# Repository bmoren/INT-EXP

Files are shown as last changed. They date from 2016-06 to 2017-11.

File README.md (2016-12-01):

# INT EXP
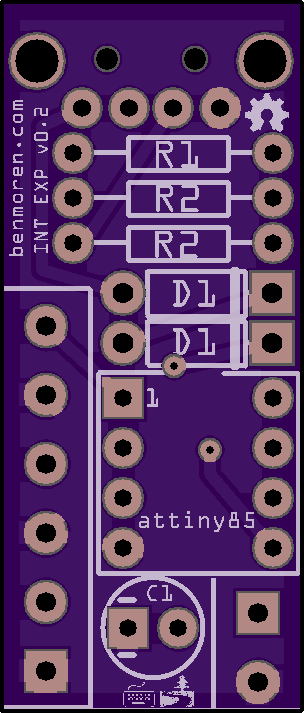
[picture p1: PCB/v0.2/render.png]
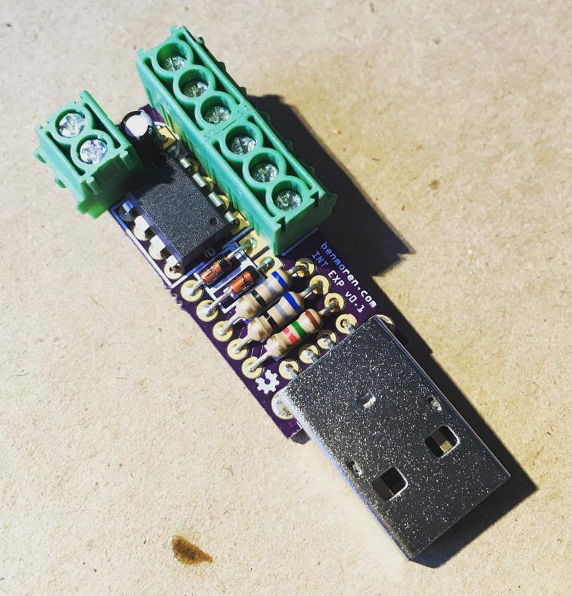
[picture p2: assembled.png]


screen &amp; physical interaction experimentation board

based on [v-usb](https://www.obdev.at/products/vusb/index.html) and the [ATtiny85](http://www.atmel.com/devices/attiny85.aspx)

with thanks to the [easy logger project](https://www.obdev.at/products/vusb/easylogger.html) and the [4 key keyboard project](http://blog.flipwork.nl/?x=entry:entry100224-003937)

[Build of Materials](https://docs.google.com/spreadsheets/d/1fC4rKzH0t7pgVtuNgmvmoYLOOsRQa8CITz7sNQLkrys/edit#gid=0)

### to compile and upload:
1. install [crosspack](https://www.obdev.at/products/crosspack/index.html)
1. pop an [ATtiny85](http://www.atmel.com/devices/attiny85.aspx) into the [usbtiny](https://www.sparkfun.com/products/11801) programmer
1. `cd` to this directory
1. `make fuse` Make the temporary 3 pin fuses with i/o on pin 4 for testing, (For the final fuse config, see below.)
1. `make flash` Flash the main.c file to the board.
1. `make resetfuse`
  + uses the final 4 pin i/o for final deployment. NOTE: this will disable the ATtiny from being re-programmable without a high voltage programmer. This must be completed after `make flash` or you will not be able to program the board!
1. `make clean` Delete all of the files used to build the main.hex file for programming.

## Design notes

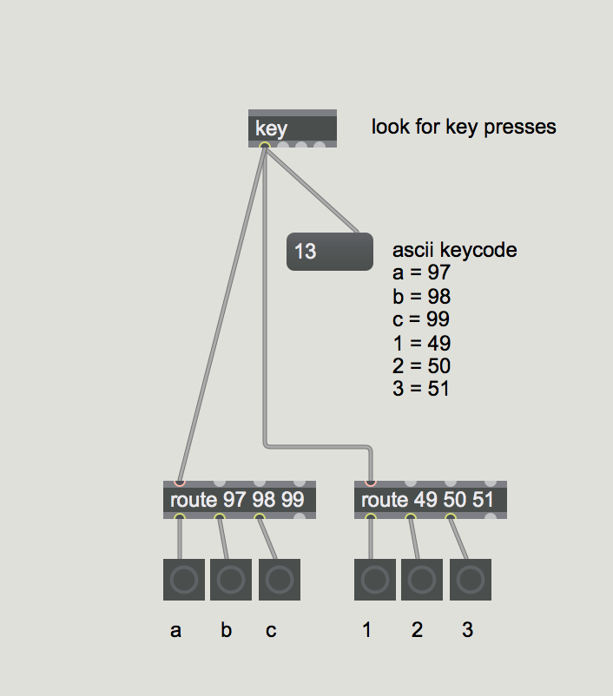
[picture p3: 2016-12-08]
examples/MAX-MSP/maxmsp.png

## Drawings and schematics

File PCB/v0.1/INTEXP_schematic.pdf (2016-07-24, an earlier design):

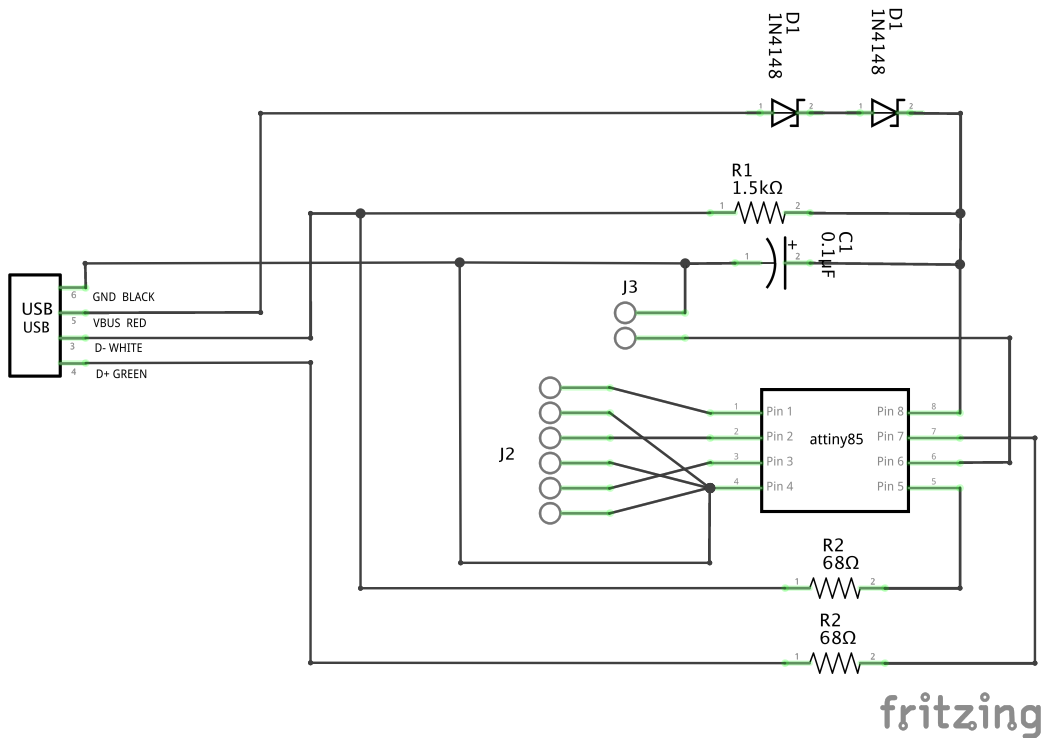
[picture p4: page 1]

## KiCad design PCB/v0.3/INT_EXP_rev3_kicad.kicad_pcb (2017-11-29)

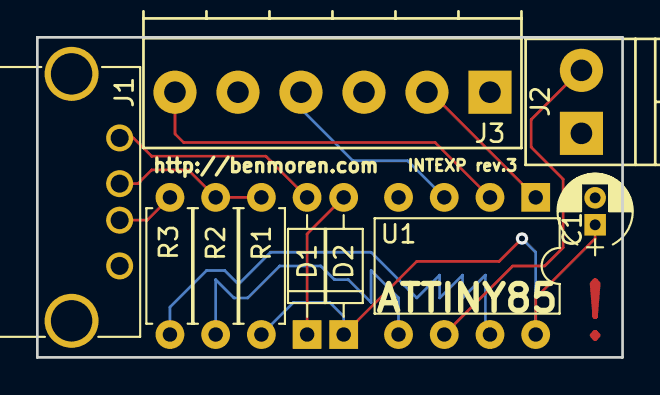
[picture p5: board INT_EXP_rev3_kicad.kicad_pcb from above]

Board: 2 copper layers, 32.5 x 17.8 mm, 10 parts (0 on the bottom side), 12 nets.

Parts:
C1: 0.1uf; CP_Radial_D4.0mm_P1.50mm
D1, D2: 1N4148; D_DO-35_SOD27_P7.62mm_Horizontal
J1: USB_A
J2: TOGGLE; TerminalBlock_Phoenix_PT-3.5mm_2pol
J3: ABC123; TerminalBlock_Phoenix_PT-3.5mm_6pol
R1: 1.5k; R_Axial_DIN0207_L6.3mm_D2.5mm_P7.62mm_Horizontal
R2, R3: 68; R_Axial_DIN0207_L6.3mm_D2.5mm_P7.62mm_Horizontal
U1: ATTINY85-20PU; DIP-8_W7.62mm

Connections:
GNDREF: C1.2, J1.4, J2.1, J3.1, J3.3, J3.5, U1.4
unnamed: C1.1, D2.1, R1.1, U1.8
unnamed: D1.1, D2.2
unnamed: D1.2, J1.1
unnamed: J1.2, R1.2, R2.2
unnamed: J1.3, R3.2
unnamed: J2.2, U1.6
unnamed: J3.2, U1.1
unnamed: J3.4, U1.3
unnamed: J3.6, U1.2
unnamed: R2.1, U1.5
unnamed: R3.1, U1.7

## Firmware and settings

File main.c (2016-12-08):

/* Name: main.c
 * Project: abc-123-intExp
 * Author: Ben Moren http://benmoren.com,
 * Thanks to Flip van den Berg - www.flipwork.nl - for a similar project which served as reference and a starting point for this project.
 * Creation Date: February 2010
 * Based on V-USB drivers from Objective Developments - http://www.obdev.at/products/vusb/index.html
 */


/*

IMPORTANT: 	This project uses fuse settings that disable the reset pin in order to use it as an IO pin.
			This means that if you can only re-program the AVR afterwards using High Voltage Serial Programming (HVSP)
			If you have a programmer that only supports ISP make sure to upload the firmware before setting the reset-disable fuse!

Working fuse setting on ATTiny45/85:

//to disable reset and enable 4 I/O
EXTENDED: 0xFF
HIGH:	 0x5F
LOW:	 0xC1

//for testing with 3 pins of I/O
EXTENDED: 0xFF
HIGH:	 0xdF
LOW:	 0xC1

*/

#include <avr/io.h>
#include <avr/wdt.h>
#include <avr/eeprom.h>
#include <avr/interrupt.h>
#include <avr/pgmspace.h>
#include <util/delay.h>
#include <stdlib.h>

#include "usbdrv/usbdrv.h"

#define BUTTON_PORT_B1 PORTB       /* PORTx - register for BUTTON 1 output */
#define BUTTON_PIN_B1 PINB         /* PINx - register for BUTTON 1 input */
#define BUTTON_BIT_B1 PB1          /* bit for BUTTON 1 input/output */

#define BUTTON_PORT_B2 PORTB       /* PORTx - register for BUTTON 2 output */
#define BUTTON_PIN_B2 PINB         /* PINx - register for BUTTON 2 input */
#define BUTTON_BIT_B2 PB4          /* bit for BUTTON 2 input/output */

#define BUTTON_PORT_B3 PORTB       /* PORTx - register for BUTTON 3 output */
#define BUTTON_PIN_B3 PINB         /* PINx - register for BUTTON 3 input */
#define BUTTON_BIT_B3 PB5          /* bit for BUTTON 3 input/output */

#define BUTTON_PORT_B4 PORTB       /* PORTx - register for BUTTON 4 output */
#define BUTTON_PIN_B4 PINB         /* PINx - register for BUTTON 4 input */
#define BUTTON_BIT_B4 PB3          /* bit for BUTTON 4 input/output */

/* ------------------------------------------------------------------------- */

static uchar    reportBuffer[8] = {0,0,0,0,0,0,0,0};    /* buffer for HID reports */

/* Reportbuffer format:

	0  Modifier byte
	1  reserved
	2  keycode array (0)
	3  keycode array (1)
	4  keycode array (2)
	5  keycode array (3)
	6  keycode array (4)
	7  keycode array (5)

	<< This is the standard usb-keyboard reportbuffer. It allows for 6 simultaneous keypresses to be detected (excl. modifier keys). In this application we only use 1, so the last 5 bytes in this buffer will always remain 0. >>
	<< I decided not to optimize this in order to make it easy to add extra keys that can be pressed simultaneously>>

   Modifier byte: 8 bits, each individual bit represents one of the modifier keys.

   	bit0  LEFT CTRL		(1<<0)
	bit1  LEFT SHIFT	(1<<1)
	bit2  LEFT ALT		(1<<2)
	bit3  LEFT GUI		(1<<3)
	bit4  RIGHT CTRL	(1<<4)
	bit5  RIGHT SHIFT	(1<<5)
	bit6  RIGHT ALT		(1<<6)
	bit7  RIGHT GUI		(1<<7)

	an example of a reportBuffer for a CTRL+ALT+Delete keypress:

	{((1<<0)+(1<<2)),0,76,0,0,0,0,0}

	the first byte holds both the LEFT CTRL and LEFT  modifier keys the 3rd byte holds the delete key (== decimal 76)

*/

static uchar    idleRate;           /* in 4 ms units */
static uchar    newReport = 0;		/* current report */

static uchar    buttonState_B1 = 3;		/*  stores state of button 0 */
static uchar    buttonState_B2 = 3;		/*  stores state of button 1 */
static uchar    buttonState_B3 = 3;		/*  stores state of button 2 */
static uchar    buttonState_B4 = 3;		/*  stores state of button 3 */

static uchar    buttonChanged_B1;
static uchar    buttonChanged_B2;
static uchar    buttonChanged_B3;
static uchar    buttonChanged_B4;

static uchar	debounceTimeIsOver = 1;	/* for switch debouncing */

static uchar  abc123 = 1; //start in 123 mode



/* ------------------------------------------------------------------------- */

const PROGMEM char usbHidReportDescriptor[USB_CFG_HID_REPORT_DESCRIPTOR_LENGTH] = {
    0x05, 0x01,                    // USAGE_PAGE (Generic Desktop)
    0x09, 0x06,                    // USAGE (Keyboard)
    0xa1, 0x01,                    // COLLECTION (Application)
    0x05, 0x07,                    //   USAGE_PAGE (Keyboard)
    0x19, 0xe0,                    //   USAGE_MINIMUM (Keyboard LeftControl)
    0x29, 0xe7,                    //   USAGE_MAXIMUM (Keyboard Right GUI)
    0x15, 0x00,                    //   LOGICAL_MINIMUM (0)
    0x25, 0x01,                    //   LOGICAL_MAXIMUM (1)
    0x75, 0x01,                    //   REPORT_SIZE (1)
    0x95, 0x08,                    //   REPORT_COUNT (8)
    0x81, 0x02,                    //   INPUT (Data,Var,Abs)	** Modifier Byte **
    0x95, 0x01,                    //   REPORT_COUNT (1)
    0x75, 0x08,                    //   REPORT_SIZE (8)
    0x81, 0x03,                    //   INPUT (Cnst,Var,Abs)	** Reserved Byte **
    0x95, 0x05,                    //   REPORT_COUNT (5)
    0x75, 0x01,                    //   REPORT_SIZE (1)
    0x05, 0x08,                    //   USAGE_PAGE (LEDs)
    0x19, 0x01,                    //   USAGE_MINIMUM (Num Lock)
    0x29, 0x05,                    //   USAGE_MAXIMUM (Kana)
    0x91, 0x02,                    //   OUTPUT (Data,Var,Abs)	** LED Report **
    0x95, 0x01,                    //   REPORT_COUNT (1)
    0x75, 0x03,                    //   REPORT_SIZE (3)
    0x91, 0x03,                    //   OUTPUT (Cnst,Var,Abs)	** LED Report Padding **
    0x95, 0x06,                    //   REPORT_COUNT (6)		** here we define the maximum number of simultaneous keystrokes we can detect **
    0x75, 0x08,                    //   REPORT_SIZE (8)
    0x15, 0x00,                    //   LOGICAL_MINIMUM (0)
    0x25, 0x65,                    //   LOGICAL_MAXIMUM (101)
    0x05, 0x07,                    //   USAGE_PAGE (Keyboard)
    0x19, 0x00,                    //   USAGE_MINIMUM (Reserved (no event indicated))
    0x29, 0x65,                    //   USAGE_MAXIMUM (Keyboard Application)
    0x81, 0x00,                    //   INPUT (Data,Ary,Abs)	** Key arrays (6 bytes) **
    0xc0                           // END_COLLECTION
};

static void timerPoll(void)
{
	static unsigned int timerCnt;

    if(TIFR & (1 << TOV1)){
        TIFR = (1 << TOV1); /* clear overflow */
        if(++timerCnt >= 5){       // 5/63 sec delay for switch debouncing
			timerCnt = 0;
			debounceTimeIsOver = 1;
        }
    }
}

static void buildReport(void){

	uchar key;

	if(newReport == 0){
		if (buttonChanged_B1 == 1){
      if (buttonState_B1 != 0){ // if button 1 is released
				// key = 0; //button released event
        abc123 = 0;
			}else { //if button 1 is pressed
				// key = 30; // key = '1'
        abc123 = 1;
	    	}
			buttonChanged_B1 = 0;
			// reportBuffer[2] = key;
		}


		if (buttonChanged_B2 == 1){
      if (buttonState_B2 != 0){ // if button 2 is pressed
				key = 0; //button released event
			}else {
        if (abc123 == 1){
				  key = 30; // key = '1'
        }else{
          key = 4; //key = 'a'
        }
			}
			buttonChanged_B2 = 0;
    	reportBuffer[2] = key;
    }
		if(buttonChanged_B3 == 1){
      if (buttonState_B3 != 0){ // if button 3 is pressed
				key = 0; //button released event
			}else{
        if (abc123 == 1){
  				key = 32; // key = '3'
        }else{
          key = 6; //key = 'c'
        }
			}
			buttonChanged_B3 = 0;
			reportBuffer[3] = key;
	  }

		if(buttonChanged_B4 == 1){
      if (buttonState_B4 != 0){ // if button 4 is pressed
				key = 0; //button released event
			}else{
        if(abc123 == 1){
          key = 31;  // key = '2'
        }else{
          key = 5; //key = 'b'
        }
    	}
			buttonChanged_B4 = 0;
    	reportBuffer[4] = key;
    }

		newReport = 1;; //if no button has changed, the previous report will be sent
	}
}

static void checkButtonChange(void) {

	uchar tempButtonValue_B1 = bit_is_set(BUTTON_PIN_B1, BUTTON_BIT_B1); //status of switch is stored in tempButtonValue
	uchar tempButtonValue_B2 = bit_is_set(BUTTON_PIN_B2, BUTTON_BIT_B2); //status of switch is stored in tempButtonValue
	uchar tempButtonValue_B3 = bit_is_set(BUTTON_PIN_B3, BUTTON_BIT_B3);  //status of switch is stored in tempButtonValue
	uchar tempButtonValue_B4 = bit_is_set(BUTTON_PIN_B4, BUTTON_BIT_B4);  //status of switch is stored in tempButtonValue

	if (tempButtonValue_B1 != buttonState_B1){ //if status has changed
		buttonState_B1 = tempButtonValue_B1;	// change buttonState to new state
		debounceTimeIsOver = 0;	// debounce timer starts
		newReport = 0; // initiate new report
		buttonChanged_B1 = 1;
	}
	if (tempButtonValue_B2 != buttonState_B2){ //if status has changed
		buttonState_B2 = tempButtonValue_B2;	// change buttonState to new state
		debounceTimeIsOver = 0;	// debounce timer starts
		newReport = 0; // initiate new report
		buttonChanged_B2 = 1;
	}
	if (tempButtonValue_B3 != buttonState_B3){ //if status has changed
		buttonState_B3 = tempButtonValue_B3;	// change buttonState to new state
		debounceTimeIsOver = 0;	// debounce timer starts
		newReport = 0; // initiate new report
		buttonChanged_B3 = 1;
	}
	if (tempButtonValue_B4 != buttonState_B4){ //if status has changed
		buttonState_B4 = tempButtonValue_B4;	// change buttonState to new state
		debounceTimeIsOver = 0;	// debounce timer starts
		newReport = 0; // initiate new report
		buttonChanged_B4 = 1;
	}

}

/* ------------------------------------------------------------------------- */

static void timerInit(void)
{
    TCCR1 = 0x0b;           /* select clock: 16.5M/1k -> overflow rate = 16.5M/256k = 62.94 Hz */
}

/* -------------------------------------------------------------------------------- */
/* ------------------------ interface to USB driver ------------------------ */
/* -------------------------------------------------------------------------------- */

uchar	usbFunctionSetup(uchar data[8])
{
usbRequest_t    *rq = (void *)data;

    usbMsgPtr = reportBuffer;
    if((rq->bmRequestType & USBRQ_TYPE_MASK) == USBRQ_TYPE_CLASS){    /* class request type */
        if(rq->bRequest == USBRQ_HID_GET_REPORT){  /* wValue: ReportType (highbyte), ReportID (lowbyte) */
            /* we only have one report type, so don't look at wValue */
            buildReport();
            return sizeof(reportBuffer);
        }else if(rq->bRequest == USBRQ_HID_GET_IDLE){
            usbMsgPtr = &idleRate;
            return 1;
        }else if(rq->bRequest == USBRQ_HID_SET_IDLE){
            idleRate = rq->wValue.bytes[1];
        }
    }else{
        /* no vendor specific requests implemented */
    }
	return 0;
}

/* ------------------------------------------------------------------------- */
/* ------------------------ Oscillator Calibration ------------------------- */
/* ------------------------------------------------------------------------- */

/* Calibrate the RC oscillator to 8.25 MHz. The core clock of 16.5 MHz is
 * derived from the 66 MHz peripheral clock by dividing. Our timing reference
 * is the Start Of Frame signal (a single SE0 bit) available immediately after
 * a USB RESET. We first do a binary search for the OSCCAL value and then
 * optimize this value with a neighboorhod search.
 * This algorithm may also be used to calibrate the RC oscillator directly to
 * 12 MHz (no PLL involved, can therefore be used on almost ALL AVRs), but this
 * is wide outside the spec for the OSCCAL value and the required precision for
 * the 12 MHz clock! Use the RC oscillator calibrated to 12 MHz for
 * experimental purposes only!
 */
static void calibrateOscillator(void)
{
uchar       step = 128;
uchar       trialValue = 0, optimumValue;
int         x, optimumDev, targetValue = (unsigned)(1499 * (double)F_CPU / 10.5e6 + 0.5);

    /* do a binary search: */
    do{
        OSCCAL = trialValue + step;
        x = usbMeasureFrameLength();    /* proportional to current real frequency */
        if(x < targetValue)             /* frequency still too low */
            trialValue += step;
        step >>= 1;
    }while(step > 0);
    /* We have a precision of +/- 1 for optimum OSCCAL here */
    /* now do a neighborhood search for optimum value */
    optimumValue = trialValue;
    optimumDev = x; /* this is certainly far away from optimum */
    for(OSCCAL = trialValue - 1; OSCCAL <= trialValue + 1; OSCCAL++){
        x = usbMeasureFrameLength() - targetValue;
        if(x < 0)
            x = -x;
        if(x < optimumDev){
            optimumDev = x;
            optimumValue = OSCCAL;
        }
    }
    OSCCAL = optimumValue;
}
/*
Note: This calibration algorithm may try OSCCAL values of up to 192 even if
the optimum value is far below 192. It may therefore exceed the allowed clock
frequency of the CPU in low voltage designs!
You may replace this search algorithm with any other algorithm you like if
you have additional constraints such as a maximum CPU clock.
For version 5.x RC oscillators (those with a split range of 2x128 steps, e.g.
ATTiny25, ATTiny45, ATTiny85), it may be useful to search for the optimum in
both regions.
*/

void    hadUsbReset(void)
{
    calibrateOscillator();
    eeprom_write_byte(0, OSCCAL);   /* store the calibrated value in EEPROM byte 0*/
}


/* ------------------------------------------------------------------------- */
/* --------------------------------- main ---------------------------------- */
/* ------------------------------------------------------------------------- */

int main(void)
{
uchar   i;
uchar   calibrationValue;

	do {} while (!eeprom_is_ready());
    calibrationValue = eeprom_read_byte(0); /* calibration value from last time */
    if(calibrationValue != 0xff){
        OSCCAL = calibrationValue;
    }

    usbInit();
    usbDeviceDisconnect();  /* enforce re-enumeration, do this while interrupts are disabled! */
    i = 0;
    while(--i){             /* fake USB disconnect for > 250 ms */
        wdt_reset();
        _delay_ms(1);
    }
    usbDeviceConnect();

    wdt_enable(WDTO_2S);

	/* turn on internal pull-up resistor for the switches */
    BUTTON_PORT_B1 |= _BV(BUTTON_BIT_B1);
	BUTTON_PORT_B2 |= _BV(BUTTON_BIT_B2);
	BUTTON_PORT_B3 |= _BV(BUTTON_BIT_B3);
	BUTTON_PORT_B4 |= _BV(BUTTON_BIT_B4);

    timerInit();


    sei();

    for(;;){    /* main event loop */
        wdt_reset();
        usbPoll();
		if (debounceTimeIsOver == 1){
			checkButtonChange();
		}

		if(usbInterruptIsReady() && newReport == 0){ /* we can send another report */
        	buildReport();
           	usbSetInterrupt(reportBuffer, sizeof(reportBuffer));
        	}

		timerPoll();
	}
   	return 0;
}

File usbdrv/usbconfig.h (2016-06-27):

/* Name: usbconfig.h
 * Project: V-USB, virtual USB port for Atmel's(r) AVR(r) microcontrollers
 * Author: Christian Starkjohann
 * Creation Date: 2005-04-01
 * Tabsize: 4
 * Copyright: (c) 2005 by OBJECTIVE DEVELOPMENT Software GmbH
 * License: GNU GPL v2 (see License.txt), GNU GPL v3 or proprietary (CommercialLicense.txt)
 * This Revision: $Id: usbconfig-prototype.h 767 2009-08-22 11:39:22Z cs $
 */

#ifndef __usbconfig_h_included__
#define __usbconfig_h_included__


/* ---------------------------- Hardware Config ---------------------------- */

#define USB_CFG_IOPORTNAME      B
/* This is the port where the USB bus is connected. When you configure it to
 * "B", the registers PORTB, PINB and DDRB will be used.
 */
#define USB_CFG_DMINUS_BIT      0
/* This is the bit number in USB_CFG_IOPORT where the USB D- line is connected.
 * This may be any bit in the port.
 */
#define USB_CFG_DPLUS_BIT       2
/* This is the bit number in USB_CFG_IOPORT where the USB D+ line is connected.
 * This may be any bit in the port. Please note that D+ must also be connected
 * to interrupt pin INT0! [You can also use other interrupts, see section
 * "Optional MCU Description" below, or you can connect D- to the interrupt, as
 * it is required if you use the USB_COUNT_SOF feature. If you use D- for the
 * interrupt, the USB interrupt will also be triggered at Start-Of-Frame
 * markers every millisecond.]
 */
#define USB_CFG_CLOCK_KHZ       (F_CPU/1000)
/* Clock rate of the AVR in kHz. Legal values are 12000, 12800, 15000, 16000,
 * 16500 and 20000. The 12.8 MHz and 16.5 MHz versions of the code require no
 * crystal, they tolerate +/- 1% deviation from the nominal frequency. All
 * other rates require a precision of 2000 ppm and thus a crystal!
 * Default if not specified: 12 MHz
 */
#define USB_CFG_CHECK_CRC       0
/* Define this to 1 if you want that the driver checks integrity of incoming
 * data packets (CRC checks). CRC checks cost quite a bit of code size and are
 * currently only available for 18 MHz crystal clock. You must choose
 * USB_CFG_CLOCK_KHZ = 18000 if you enable this option.
 */

/* ----------------------- Optional Hardware Config ------------------------ */

/* #define USB_CFG_PULLUP_IOPORTNAME   D */
/* If you connect the 1.5k pullup resistor from D- to a port pin instead of
 * V+, you can connect and disconnect the device from firmware by calling
 * the macros usbDeviceConnect() and usbDeviceDisconnect() (see usbdrv.h).
 * This constant defines the port on which the pullup resistor is connected.
 */
/* #define USB_CFG_PULLUP_BIT          4 */
/* This constant defines the bit number in USB_CFG_PULLUP_IOPORT (defined
 * above) where the 1.5k pullup resistor is connected. See description
 * above for details.
 */

/* --------------------------- Functional Range ---------------------------- */
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

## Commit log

2016-06-27 abc/123 switch working
2016-06-27 add final fuse to makefile
2016-07-24 added v0.1 of the PCB
    [INT_EXP_v0.1.fzz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]
2016-08-07 added board image and changed name of repo
2016-08-26 v0.2 pcb
    [INT_EXP_v0.1.fzz, INT_EXP_v0.2.fzz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]
